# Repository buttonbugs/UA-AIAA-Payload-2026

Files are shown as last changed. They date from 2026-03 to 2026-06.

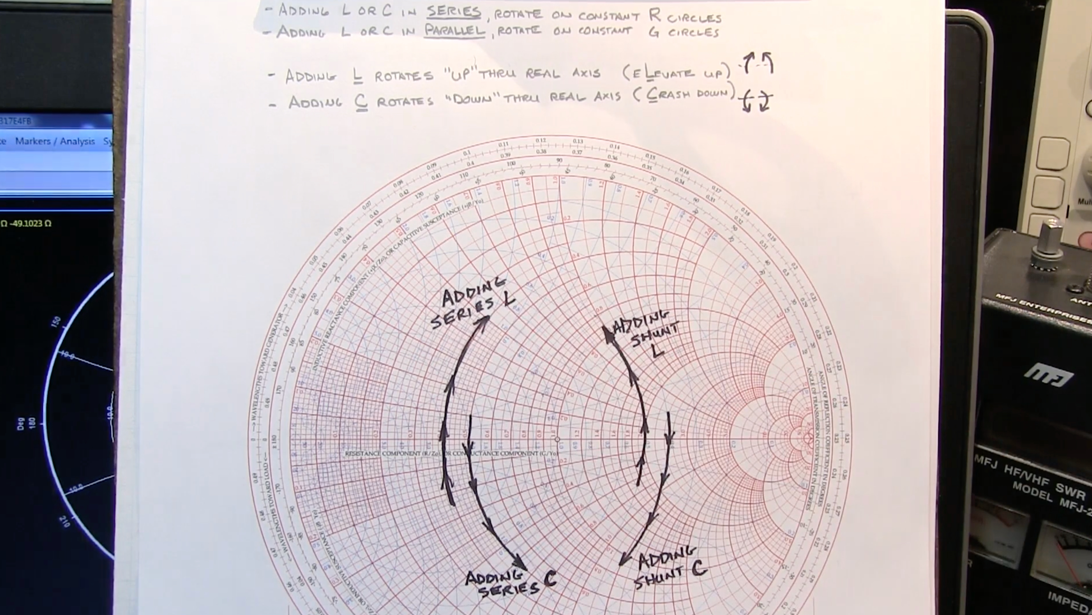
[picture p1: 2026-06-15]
Antenna_calculation/README/Switch Chart Theory.jpeg

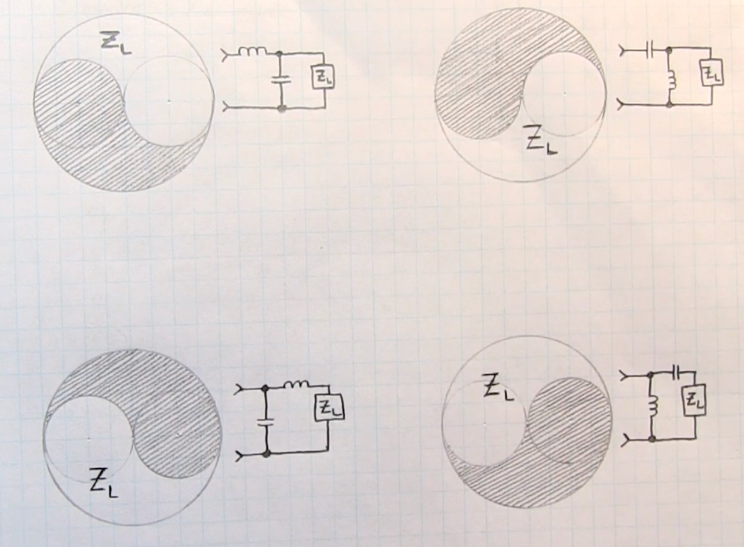
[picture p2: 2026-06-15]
Antenna_calculation/README/Available Range.jpeg

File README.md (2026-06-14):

# UA AIAA Payload 2026

This repository includes the payload codes for the [UA AIAA](https://uaaiaa.org/) Rocket Competition Team.

## Software

**VS Code Extension:** [PlatformIO IDE](https://marketplace.visualstudio.com/items?itemName=platformio.platformio-ide)

**Framework:** Arduino

### Libraries

| Libraries | Installation |
| - | - |
| DFRobot_OzoneSensor | [DFRobot Website](https://wiki.dfrobot.com/Gravity_IIC_Ozone_Sensor_(0-10ppm)%20SKU_SEN0321) |
| ICM_20948 | PlatformIO &rarr; Libraries |
| Adafruit_BME280 | PlatformIO &rarr; Libraries |
| SD | PlatformIO &rarr; Libraries |
| Adafruit_SGP40 | PlatformIO &rarr; Libraries |
| WatchDog | [Arduino Built-In Library](https://docs.arduino.cc/libraries/watchdog/) |

## Hardware

### Pin Configuration

**Pin Configuration for I²C and SPI**

| Pin Name | Pin No.| Protocol |
| - | - | - |
| SDA | A4 | I²C |
| SCL | A5 | I²C |
| CLK / SCK | D13 | SPI |
| DO / MISO | D12 | SPI |
| DI / MOSI | D11 | SPI |
| CS for the SD Card Reader | D10 (or any) | SPI |

**Pin Configuration for Ultrasonic Sensor**

| Sensor | Trigger Pin | Echo Pin |
| - | - | - |
| Ultrasonic Sensor 1 | D2 | D3 |
| Ultrasonic Sensor 2 | D4 | D5 |
| Ultrasonic Sensor 3 | D6 | D7 |

**Other Pin Configuration**

| Sensor | Signal Pin |
| - | - |
| SW-18010P 1 (Horizontal)  | A6 |
| SW-18010P 2 (Vertical) | A7 |

Reference: [Arduino Nano Every Full Pinout Diagram (Official)](https://content.arduino.cc/assets/Pinout-NANOevery_latest.pdf)

### Electronics

| Electronics | Description | Voltage | Protocol | On PCB |
| - | - | - | - | - |
| Microcontroller | [Arduino Nano Every](https://store-usa.arduino.cc/products/nano-every) | 5V | - | Y |
| SD Card Reader | [Adafruit MicroSD Card Breakout ADA254](https://www.amazon.com/Adafruit-MicroSD-Breakout-Board-ADA254/dp/B00NAY2NAI/) | 5V | SPI | Y |
| Ozone Sensor | [DFRobot Gravity: IIC Ozone Sensor V1.0](https://wiki.dfrobot.com/Gravity_IIC_Ozone_Sensor_(0-10ppm)%20SKU_SEN0321) | 3.3V - 5.5V | I²C | N |
| VOC Sensor | [Waveshare SGP40 VOC Sensor](https://www.waveshare.com/wiki/SGP40_VOC_Sensor#Test_the_codes) | 3.3V or 5V | I²C | N |
| IMU Sensor | [SparkFun 9DoF IMU Breakout - ICM 20948](https://www.amazon.com/SparkFun-Breakout-ICM-20948-connection-Accelerometer-Magnetometer/dp/B07VNV3WKL/) | 1.95 V - 3.6 V | I²C | Y |
| BME280 Sensor | [Starry GY-BME280 5V](https://www.amazon.com/Starry-Atmospheric-Pressure-Temperature-GY-BME280/dp/B0DRCNNBF3/) | 5V | I²C | Y |
| Ultrasonic Sensor | HC-SR04 | 5V | - | N |
| Vibration Sensor | [SW-18020P](https://www.adafruit.com/product/2384) | &le; 12V | - | N |

## PCB

### PCB resources

Arduino footprints and symbols: [Alarm-Siren/arduino-kicad-library](https://github.com/Alarm-Siren/arduino-kicad-library)

PCB manufacturer: [JLCPCB](https://jlcpcb.com/)

### How to generate Gerber and Drill files in KiCAD 9

See https://jlcpcb.com/help/article/how-to-generate-gerber-and-drill-files-in-kicad-9

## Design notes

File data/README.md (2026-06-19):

# Data Processing

To calculate the speed of sound ($c$) in humid air, use the Cramer equation or the fundamental Laplace-adiabatic equation adjusted for wet air. The most accurate direct calculation requires finding the isentropic exponent (ratio of specific heats) and the gas constant for the specific air mixture. [^1] [^2] 
Here is the step-by-step method to calculate it.

## 1. Find Saturation Vapor Pressure [^3]

First, calculate the saturation vapor pressure of water ($p_{sat}$) in Pascals using the temperature in Kelvin ($T_K$) or celsius ($T_C$).

You can use the Hardy or Buck equation:

```math
\begin{aligned}
p_{sat} &= 611.21 \cdot \exp\left(\frac{17.502 \cdot (T_K - 273.15)}{T_K - 32.18}\right)
\\
p_{sat} &= 611.21 \cdot \exp \left[ \left( 18.678 - \frac{T_C}{234.5} \right) \left( \frac{T_C}{257.14 + T_C} \right) \right]
\end{aligned}
```

## 2. Determine Actual Vapor Pressure [^4]

Multiply the saturation vapor pressure by your relative humidity ($RH$, expressed as a decimal between $0$ and $1$) to find the partial pressure of water vapor ($p_v$):

```math
p_v = \left(\frac{RH}{100}\right) \cdot p_{sat}
```

## 3. Calculate Mole Fraction of Water Vapor

Find the molar fraction of water vapor ($x_v$) by dividing the vapor pressure by the total air pressure ($p$):

```math
x_v = \frac{p_v}{p}
```

## 4. Compute Specific Gas Constant [^5]

Calculate the specific gas constant for the humid air mixture ($R_{mix}$). Dry air has a molar mass of $M_d \approx 0.028965\text{ kg/mol}$, and water vapor has $M_v \approx 0.018015\text{ kg/mol}$: [^6]

```math
\begin{aligned}
M_{mix} &= (1 - x_v) \cdot M_d + x_v \cdot M_v
\\
R_{mix} &= \frac{R_u}{M_{mix}}
\end{aligned}
```

(Where $R_u$ is the universal gas constant, $8.31446\text{ J/(mol}\cdot\text{K)}$) [^7]

## 5. Adjust the Isentropic Exponent

The ratio of specific heats ($\gamma$) changes slightly with humidity. For dry air, $\gamma_d \approx 1.400$. For water vapor, $\gamma_v \approx 1.333$. Approximate the mixture's exponent ($\gamma_{mix}$) using the mole fraction: [^8]

```math
\gamma_{mix} = (1 - x_v) \cdot 1.400 + x_v \cdot 1.333
```

## 6. Calculate Speed of Sound [^9]

Plug the mixture variables, temperature ($T$), air pressure ($p$), and density ($\rho$) into the ideal gas or hydrodynamic speed of sound formula:

```math
c = \sqrt{\frac{\gamma_{mix} \cdot p}{\rho}}
```

Alternatively, using the gas constant:

```math
c = \sqrt{\gamma_{mix} \cdot R_{mix} \cdot T}
```

## Summary

The final speed of sound in humid air is explicitly stated by the thermodynamic relationship:

```math
c = \sqrt{\frac{\gamma_{mix} \cdot p}{\rho}}
```

Where $c$ is the speed of sound in $\text{m/s}$, $\gamma_{mix}$ is the humidity-adjusted isentropic exponent, $p$ is the air pressure in $\text{Pa}$, and $\rho$ is the air density in $\text{kg/m}^3$. [^10] [^11] 

[^1]: https://www.researchgate.net/publication/352530307_Noise_Control_From_Concept_to_Application
[^2]: https://www.mh-aerotools.de/airfoils/perfred.htm
[^3]: https://turn2engineering.com/calculators/relative-humidity-calculator
[^4]: https://www.fao.org/4/x0490e/x0490e07.htm
[^5]: https://www.vaia.com/en-us/textbooks/physics/fluid-mechanics-7-edition/chapter-9/problem-46-a-one-dimensional-isentropic-airflow-has-the-foll/
[^6]: https://en.wikipedia.org/wiki/Density_of_air
[^7]: https://vulcan-cfd.larc.nasa.gov/WebPage/Documentation/AIAA-2004-0267.pdf
[^8]: https://allen.in/dn/qna/11750513
[^9]: https://allen.in/dn/qna/648202972
[^10]: https://geo.libretexts.org/Bookshelves/Oceanography/Introduction_to_Physical_Oceanography_%28Stewart%29/03%3A_The_Physical_Setting/3.6%3A_Sound_in_the_Ocean
[^11]: https://basicairdata.eu/knowledge-center/background-topics/density-and-air-temperature/

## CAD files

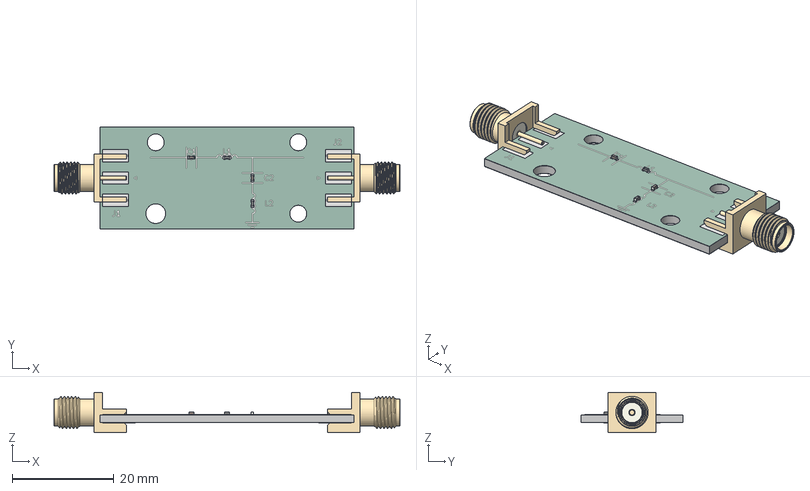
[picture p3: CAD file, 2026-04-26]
Antenna_PCB_v1/Antenna_PCB_v1.step
68.0 x 20.0 x 7.92 mm
C_0402_1005Metric x 2
L_0402_1005Metric x 2
SMA_Molex_73251-1153_EdgeMount_Horizontal x 2
Antenna_PCB_v1_copper
Antenna_PCB_v1_pad
Antenna_PCB_v1_via
Antenna_PCB_v1_silkscreen x 2
Antenna_PCB_v1_soldermask x 2
Antenna_PCB_v1_PCB

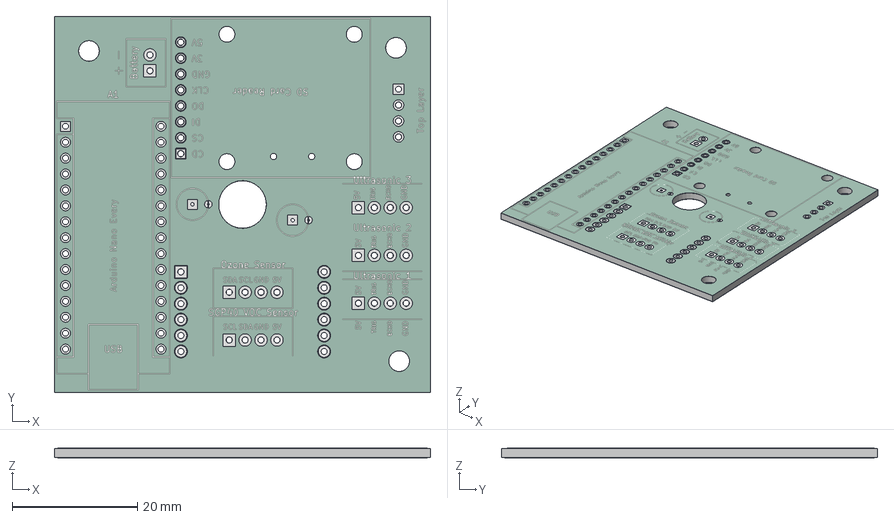
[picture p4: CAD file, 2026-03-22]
PCB_v1/Payload_2026_PCB_v1.step
60.0 x 60.0 x 1.66 mm
Payload_2026_PCB_v1_copper
Payload_2026_PCB_v1_pad
Payload_2026_PCB_v1_silkscreen x 2
Payload_2026_PCB_v1_soldermask x 2
Payload_2026_PCB_v1_PCB

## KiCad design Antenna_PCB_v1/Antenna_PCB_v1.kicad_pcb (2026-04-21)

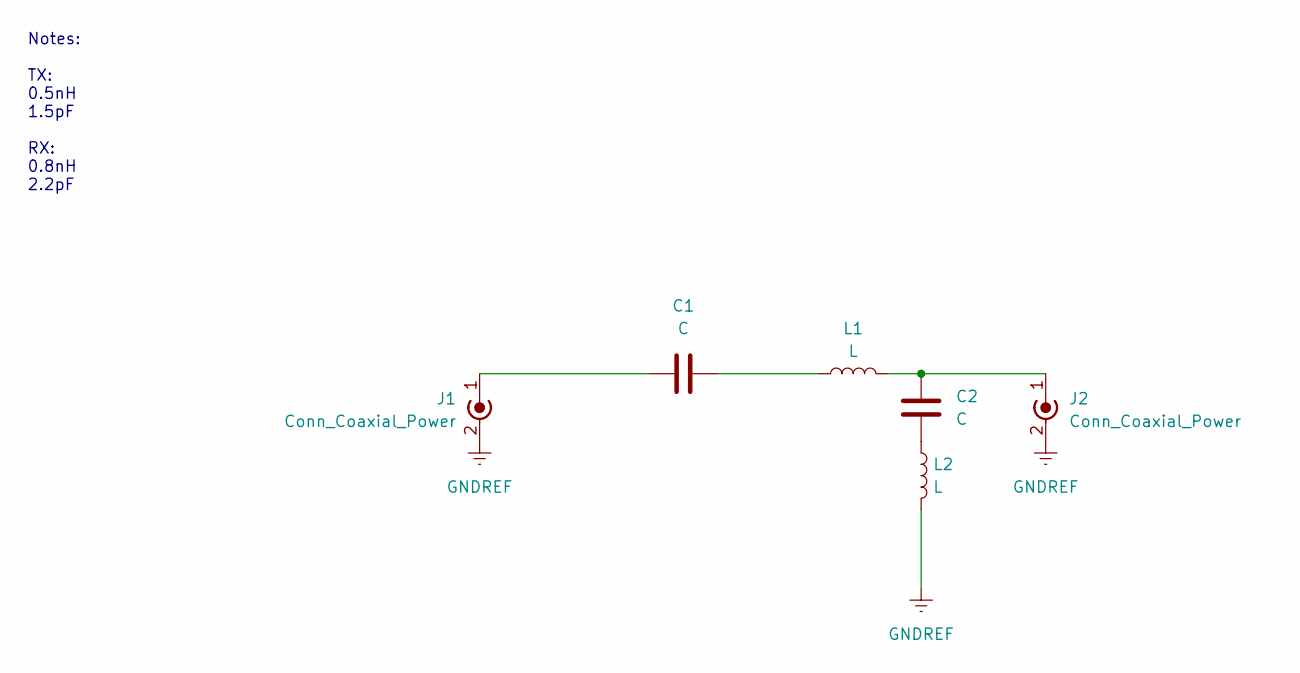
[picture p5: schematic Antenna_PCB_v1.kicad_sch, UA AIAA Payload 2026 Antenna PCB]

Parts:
C1, C2: C; C_0402_1005Metric
J1, J2: Conn_Coaxial_Power; SMA_Molex_73251-1153_EdgeMount_Horizontal
L1, L2: L; L_0402_1005Metric

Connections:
GNDREF: J1.2 (Ext), J2.2 (Ext), L2.2
unnamed: C1.2, L1.1
unnamed: C2.2, L2.1
unnamed: C1.1, J1.1 (In)
unnamed: C2.1, J2.1 (In), L1.2

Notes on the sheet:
Notes: TX: 0.5nH 1.5pF RX: 0.8nH 2.2pF

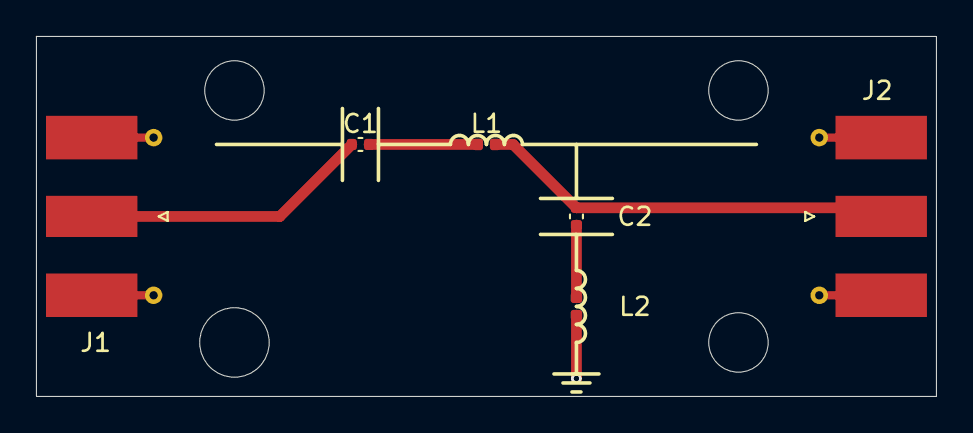
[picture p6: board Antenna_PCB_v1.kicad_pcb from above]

Board: 2 copper layers, 50.0 x 20.0 mm, 6 parts (0 on the bottom side), 5 nets.

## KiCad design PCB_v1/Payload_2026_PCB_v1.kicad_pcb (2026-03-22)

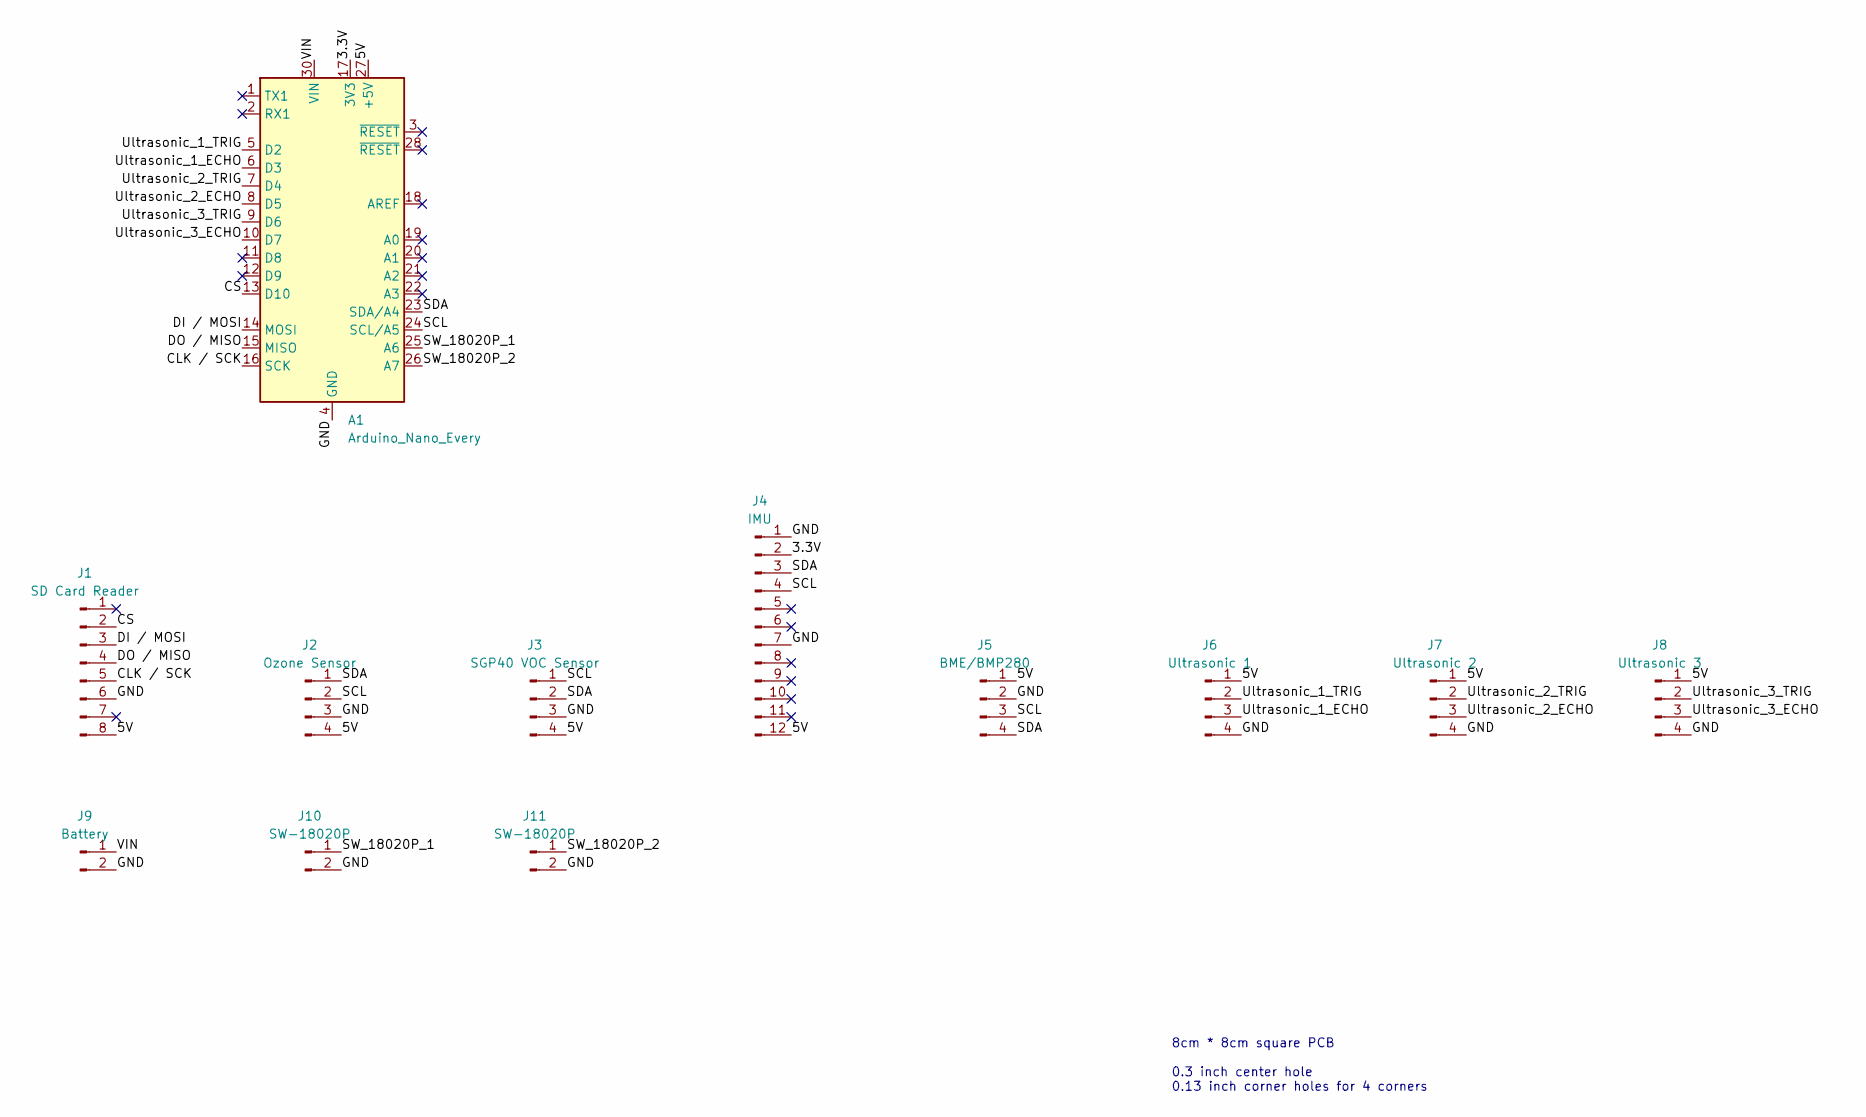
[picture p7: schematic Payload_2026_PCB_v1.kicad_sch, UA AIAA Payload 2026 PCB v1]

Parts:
A1: Arduino_Nano_Every; Arduino_Nano
J1: SD Card Reader; SD_Card_Reader
J2: Ozone Sensor; Conn_01x04_Pin
J3: SGP40 VOC Sensor; Conn_01x04_Pin
J4: IMU
J5: BME/BMP280; BME280_Sensor
J6: Ultrasonic 1; Conn_01x04_Pin
J7: Ultrasonic 2; Conn_01x04_Pin
J8: Ultrasonic 3; Conn_01x04_Pin
J9: Battery
J10, J11: SW-18020P; SW_18020P

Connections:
/3.3V: A1.17 (3V3), J4.2
/5V: A1.27 (+5V), J1.8, J2.4, J3.4, J4.12, J5.1, J6.1, J7.1, J8.1
/CLK / SCK: A1.16 (SCK), J1.5
/CS: A1.13 (D10), J1.2
/DI / MOSI: A1.14 (MOSI), J1.3
/DO / MISO: A1.15 (MISO), J1.4
/GND: A1.4 (GND), A1.29 (GND), J1.6, J2.3, J3.3, J4.1, J4.7, J5.2, J6.4, J7.4, J8.4, J9.2, J10.2, J11.2
/SCL: A1.24 (SCL/A5), J2.2, J3.1, J4.4, J5.3
/SDA: A1.23 (SDA/A4), J2.1, J3.2, J4.3, J5.4
/SW_18020P_1: A1.25 (A6), J10.1
/SW_18020P_2: A1.26 (A7), J11.1
/Ultrasonic_1_ECHO: A1.6 (D3), J6.3
/Ultrasonic_1_TRIG: A1.5 (D2), J6.2
/Ultrasonic_2_ECHO: A1.8 (D5), J7.3
/Ultrasonic_2_TRIG: A1.7 (D4), J7.2
/Ultrasonic_3_ECHO: A1.10 (D7), J8.3
/Ultrasonic_3_TRIG: A1.9 (D6), J8.2
/VIN: A1.30 (VIN), J9.1

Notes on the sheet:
8cm * 8cm square PCB 0.3 inch center hole 0.13 inch corner holes for 4 corners

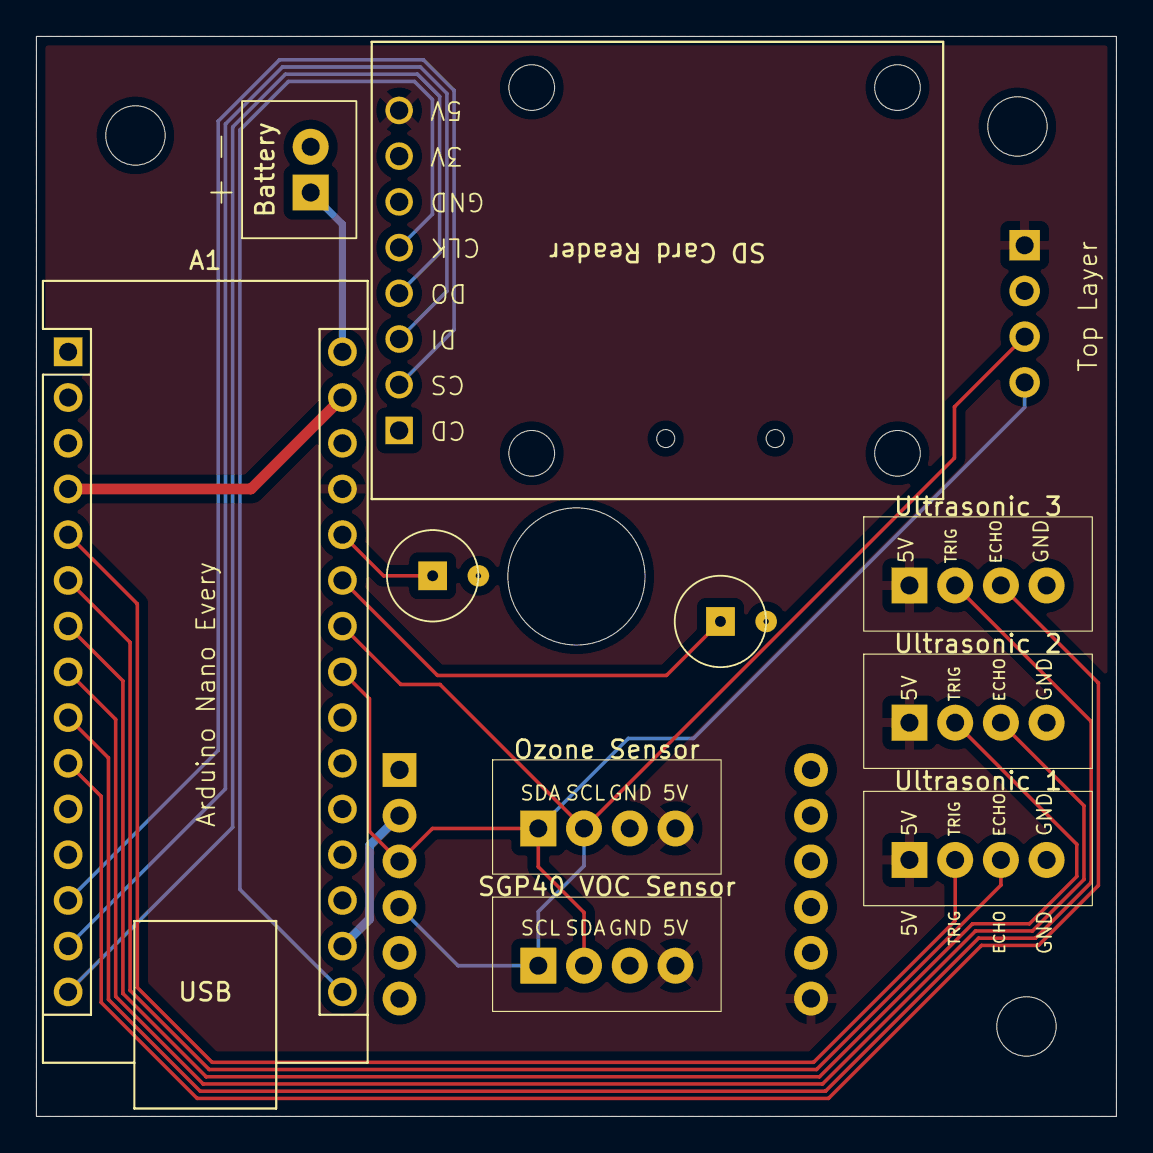
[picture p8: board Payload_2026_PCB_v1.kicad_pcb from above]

Board: 2 copper layers, 60.0 x 60.0 mm, 12 parts (0 on the bottom side), 18 nets.

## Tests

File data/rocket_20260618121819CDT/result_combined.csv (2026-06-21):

1148 | 0 | 0 | 2.0507811E+01 | 9.9707025E+02 | -2.7343748E+01 | 8.9312977E-01 | 4.1221374E-01 | -5.0152674E+00 | -2.2350000E+01 | 2.9550001E+01 | -1.3755000E+02 | 4.1687691E+01 | 3.8700001E+01 | 9.0625914E+04 | 1.3775391E+01 | 6.2800002E-01 | 0.0000000E+00 | 6.7000002E-01 | 0 | 0
2289 | 0 | 0 | 1.5136718E+01 | 1.0024413E+03 | -3.8085938E+01 | 2.9312978E+00 | -3.6641222E-01 | -3.4961832E+00 | -2.5500002E+01 | 3.5100002E+01 | -1.3785001E+02 | 4.2023155E+01 | 3.8740002E+01 | 9.0626219E+04 | 1.3751953E+01 | 6.3700002E-01 | 0.0000000E+00 | 6.7000002E-01 | 0 | 0
3432 | 0 | 0 | 1.9042969E+01 | 1.0063476E+03 | -3.9550781E+01 | -7.2519082E-01 | -1.4732825E+00 | -3.2137403E+00 | -2.4600000E+01 | 3.5400002E+01 | -1.3605000E+02 | 4.1879387E+01 | 3.8759998E+01 | 9.0621469E+04 | 1.3692383E+01 | 6.3700002E-01 | 0.0000000E+00 | 6.7799997E-01 | 0 | 0
4575 | 0 | 0 | 8.3007813E+00 | 1.0249023E+03 | -1.8554688E+01 | 2.0076337E+00 | 1.0763359E+00 | -3.5496182E+00 | -2.4000000E+01 | 3.6450001E+01 | -1.3530000E+02 | 4.2262768E+01 | 3.8770000E+01 | 9.0622703E+04 | 1.3657227E+01 | 6.2800002E-01 | 0.0000000E+00 | 6.7799997E-01 | 0 | 0
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

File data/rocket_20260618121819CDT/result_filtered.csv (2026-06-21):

Timestamp (ms) | Ozone (PPB) | Air quality (VOC) | Accelerometer X (milli-g) | Accelerometer Y (milli-g) | Accelerometer Z (milli-g) | Gyroscope X (deg/s) | Gyroscope Y (deg/s) | Gyroscope Z (deg/s) | Magnetometer X (uT) | Magnetometer Y (uT) | Magnetometer Z (uT) | IMU Temperature (C) | BME280 Temperature (C) | Pressure (Pa) | Humidity (%RH) | Ultrasonic 1 (ms) | Ultrasonic 2 (ms) | Ultrasonic 3 (ms) | Vibration 1 Period (ms) | Vibration 2 Period (ms) | 1148 | 0 | 0 | 2.0507811E+01 | 9.9707025E+02 | -2.7343748E+01 | 8.9312977E-01 | 4.1221374E-01 | -5.0152674E+00 | -2.2350000E+01 | 2.9550001E+01 | -1.3755000E+02 | 4.1687691E+01 | 3.8700001E+01 | 9.0625914E+04 | 1.3775391E+01 | 6.2800002E-01 | 0.0000000E+00 | 6.7000002E-01 | 0 | 0
2289 | 0 | 0 | 1.5136718E+01 | 1.0024413E+03 | -3.8085938E+01 | 2.9312978E+00 | -3.6641222E-01 | -3.4961832E+00 | -2.5500002E+01 | 3.5100002E+01 | -1.3785001E+02 | 4.2023155E+01 | 3.8740002E+01 | 9.0626219E+04 | 1.3751953E+01 | 6.3700002E-01 | 0.0000000E+00 | 6.7000002E-01 | 0 | 0
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

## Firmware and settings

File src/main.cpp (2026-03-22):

#include <Arduino.h>
#include "config.h"
#include "Wire.h"

#include "write_sd.h"
#include "read_vibration.h"

uint8_t voc = 0;

void setup() {
    Wire.begin();       // Important! Initialize the I2C (Inter-Integrated Circuit) communication protocol
    Serial.begin(9600);
    delay(100);
    init_sd();
}

void loop() {
    write_sd();
    delay(SAMPLE_ECHOTERVAL);
}

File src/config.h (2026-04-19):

#ifndef CONFIG
#define CONFIG

#define FILE_SIZE_LIMIT 4E9             // bytes, create another data file when the current file size exceeds the this number; 4GB = 4,294,967,296 bytes > 4E9 bytes

#define SAMPLE_ECHOTERVAL 10            // milliseconds per data sample

#define ULTRASONIC_TIMEOUT_US 30000     // microseconds, prevent the code from freezing when unable to get data from the ultrasonic sensor

#define VIBRATION_TIMEOUT_MS 1000       // milliseconds, the vibration period will be set to 0 if no vibration is detected within the timeout

#define E_DECIMAL_PLACE 7               // Scientific notation decimal places, Arduino float data types typically provide 6 to 7 decimal digits of precision

/* Pin Configuration */
// Ultrasonic Sensor
#define ULTRASONIC_1_TRIG 2
#define ULTRASONIC_1_ECHO 3
#define ULTRASONIC_2_TRIG 4
#define ULTRASONIC_2_ECHO 5
#define ULTRASONIC_3_TRIG 6
#define ULTRASONIC_3_ECHO 7

// Vibration Sensor
#define VIBRATION_SENSOR_1 A6
#define VIBRATION_SENSOR_2 A7

// SD Card Reader
#define SD_CARD_CS 10               // SD card Chip Select (set to 10 by default)

#endif

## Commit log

2026-02-15 Import "DFRobot_OzoneSensor.h" and test the ozone sensor
2026-02-15 sgp40 voc sensor test
2026-02-15 Update README.md Sensor List
2026-02-22 Sensor tests finished
2026-02-23 Finish ultrasonic sensor codes
2026-02-23 SD Card Writing Test (Failed at write_sd.cpp line 120 column 30); there might be something wrong with the wiring of IMU
    [write_sd.cpp]
2026-03-01 Fix SD card writing issue
    [write_sd.cpp]
2026-03-01 Fix voc and initial column headers
    [main.cpp, read_imu.cpp, write_sd.cpp]
2026-03-02 Create PCB_v1; import Arduino symbols
    [Payload_2026_PCB_v1.kicad_pcb, Payload_2026_PCB_v1.kicad_sch]
2026-03-02 PCB Footprints finished
    [Payload_2026_PCB_v1.kicad_sch]
2026-03-02 Finish PCB Design
    [Payload_2026_PCB_v1.kicad_pcb, Payload_2026_PCB_v1.kicad_sch]
2026-03-02 Write DOTO List in sch
    [Payload_2026_PCB_v1.kicad_sch]
2026-03-02 Update PCB layout
    [Payload_2026_PCB_v1.kicad_pcb, Payload_2026_PCB_v1.kicad_sch]
2026-03-02 Update PCB Silkscreen Labels
    [Payload_2026_PCB_v1.kicad_pcb, Payload_2026_PCB_v1.kicad_sch]
2026-03-03 Add UA AIAA Logo onto PCB
    [Payload_2026_PCB_v1.kicad_pcb]
2026-03-03 Set the VIN thickness on PCB
    [Payload_2026_PCB_v1.kicad_pcb]
2026-03-03 Add SW-18020P to the PCB; generate gerber files
    [Payload_2026_PCB_v1-B_Cu.gbl, Payload_2026_PCB_v1-B_Mask.gbs, Payload_2026_PCB_v1-B_Paste.gbp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]
2026-03-03 Update PCB 3D Model
2026-03-22 Generate Gerber files
    [Payload_2026_PCB_v1-B_Cu.gbl, Payload_2026_PCB_v1-B_Mask.gbs, Payload_2026_PCB_v1-B_Paste.gbp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]
2026-03-22 Finish ultrasonic code
2026-03-22 Update Gerber files
    [Payload_2026_PCB_v1-B_Cu.gbl, Payload_2026_PCB_v1-B_Mask.gbs, Payload_2026_PCB_v1-B_Paste.gbp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]
2026-03-22 Add another vibration sensor
    [Payload_2026_PCB_v1-B_Cu.gbl, Payload_2026_PCB_v1-B_Mask.gbs, Payload_2026_PCB_v1-B_Paste.gbp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]
2026-03-22 Finish vibration sensor code
    [config.h, read_vibration.cpp, write_sd.cpp]
2026-03-22 Add vibration sensor timeout
    [config.h, main.cpp, read_ultrasonic.cpp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]
2026-03-22 Fix PCB isolated GND caused by new vibration sensor holes
    [Payload_2026_PCB_v1-B_Cu.gbl, Payload_2026_PCB_v1-B_Mask.gbs, Payload_2026_PCB_v1-B_Paste.gbp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]
2026-04-13 Add sensor initialization debugging
2026-04-19 Create Antenna PCB
    [Antenna_PCB_v1.kicad_pcb, Antenna_PCB_v1.kicad_sch]
2026-04-19 Add holes to PCB
    [Antenna_PCB_v1-B_Cu.gbl, Antenna_PCB_v1-B_Mask.gbs, Antenna_PCB_v1-B_Paste.gbp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]
2026-04-20 Upload data sample
    [DATA_000.CSV]
2026-04-21 Fix antenna PCB circuit
    [Antenna_PCB_v1.kicad_pcb, Antenna_PCB_v1.kicad_sch]
2026-04-21 Update gerber files and 3D model
    [Antenna_PCB_v1-B_Cu.gbl, Antenna_PCB_v1-B_Mask.gbs, Antenna_PCB_v1-B_Paste.gbp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]
2026-04-26 Add KiCad temp files to gitignore
2026-04-26 Update antenna PCB 3D model
    [Antenna_PCB_v1.kicad_sch, Antenna_PCB_v1.step]
2026-06-19 Organize testing data
    [DATA_000.CSV]
2026-06-19 Upload 20260617142200CDT testing data
    [DATA_000.CSV, DATA_001.CSV, DATA_002.CSV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]
2026-06-19 Add payload starting time to config file
    [config.txt]
2026-06-19 Add data combining and filtering code
2026-06-19 Change combined and filtered data file names and locations
2026-06-19 Draw temperature and save plot to files
    [result_combined.csv, result_filtered.csv]
2026-06-19 Specify labels for temperature graph
2026-06-19 Swap BME280 temperature and IMU temperature
2026-06-19 Draw pressure and temperature dual-axis chart
2026-06-19 Add Buck equation given temperature in celsius
2026-06-19 Fix ultrasonic data naming error
2026-06-20 Draw graph for magnetic field
2026-06-21 Upload payload data
    [DATA_000.CSV, DATA_001.CSV, DATA_002.CSV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]
2026-06-21 Upload camera system gcsv data
2026-06-21 Upload GPS data
    [66UofA_G_06-18-2026_17_05_35.csv]
2026-06-21 Upload rocket camera recording
2026-06-21 Draw payload graph
    [result_combined.csv, result_filtered.csv]
2026-06-21 Set y limit to pressure graph
2026-06-21 Rotate 45 deg for axis in pressure_temp graph
2026-10-29 Add launch timer formatting
2026-10-29 Update video launch timer formatting
